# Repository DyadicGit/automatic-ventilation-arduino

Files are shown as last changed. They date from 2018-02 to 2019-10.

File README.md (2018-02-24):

# This is a Home/Flat ventilation system.
For measuring rooms air quality it uses two gas sensors MQ-9 and MQ-135 also a Thermistor for measuring temperature.
Displays gas value (unitless) and temperature (celsius) on a I2C 128x32 SSD1306 driver OLED display.
Has a two buttons:
	first button -- Toggles ON/OFF the display
	second button -- Turns on the fans for a period of time

------
Circuit:

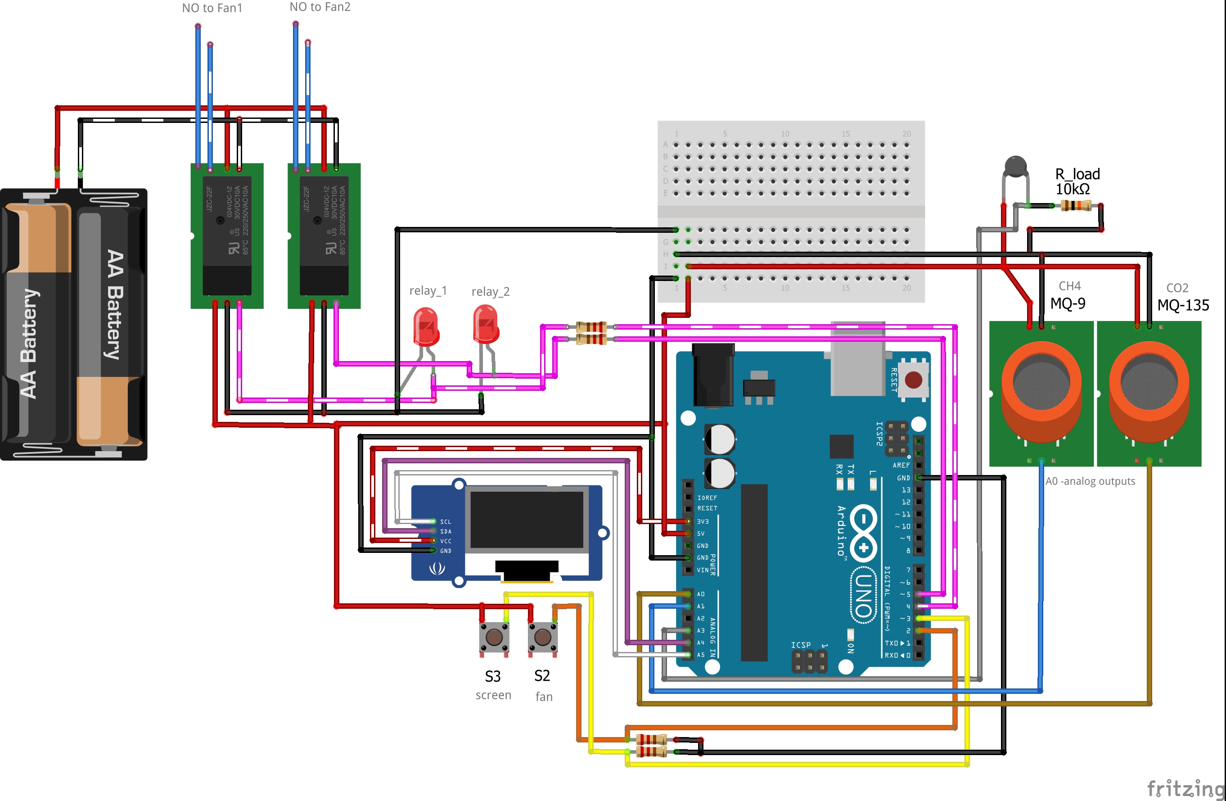
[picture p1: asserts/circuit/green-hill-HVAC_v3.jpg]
circuit: prod version circuit


## What it does?
* Automatically turns the fans ON, when the air quality goes bad (user inputs the values)
* User can turn the fans for a period of time, the remaining time is displayed on the LCD
* Toggle ON/OFF the display -- Why should it run always.

*watch a demo video below:*

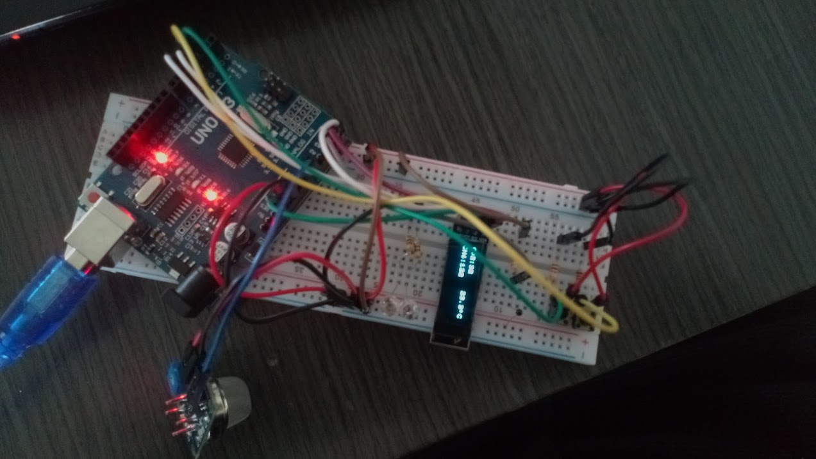
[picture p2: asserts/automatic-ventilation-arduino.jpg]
demo: open demo video (https://youtu.be/hbuPtd6k3tc)

[Demo video link](https://youtu.be/hbuPtd6k3tc)
*only one sensor in demo* :(

### Technologies used:
* For measuring temperature with a Thermistor, Steinhart–Hart equation was used
* for the OLED display [u8x8 library](https://github.com/olikraus/u8g2/wiki/u8x8reference) was used

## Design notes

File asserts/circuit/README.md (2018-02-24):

# Circuit schematics info:
Production version schematic:

prod: prod version circuit

Simulation version schematic:

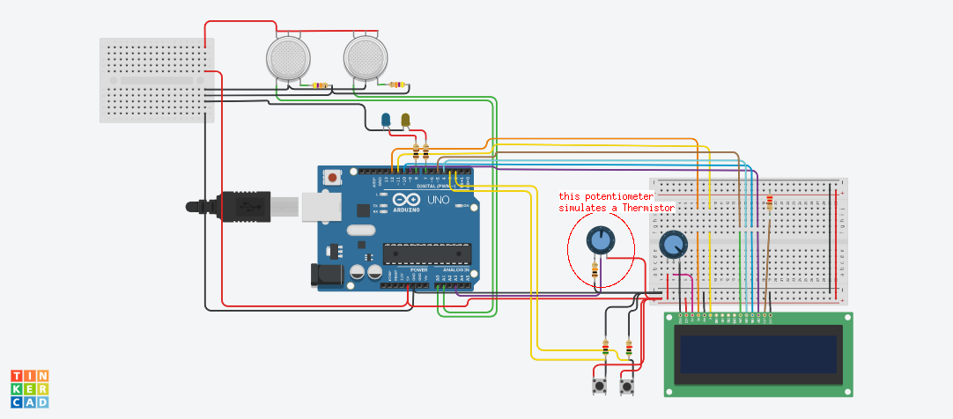
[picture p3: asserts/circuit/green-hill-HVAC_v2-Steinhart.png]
simu: simu version circuit


..Simulations where made in [Tinkercad](https://www.tinkercad.com)..
..When simulating used a potentiometer instead of the NTC thermistor, set potentiometers resistance to 10kOhm (because NTC-MF52-103 resistance is 10kOhm) also set the load resistor to 10kOhm. ..
Code for simulation is in *__asserts/other versions/main_v2-Steinhart.cpp__*
Or just test how it measures the temperature: *__asserts/other versions/test-Steinhart.cpp__*

## Bill of Materials:
1) 128x32 I2C SSD1306 OLED display

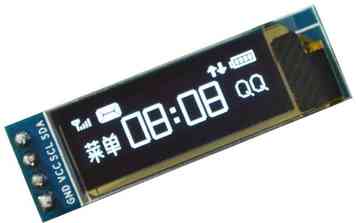
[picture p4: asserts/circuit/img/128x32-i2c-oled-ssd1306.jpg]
LCD: display


2) NTC MF52 series 103 type 10K ohm 1% Thermistor

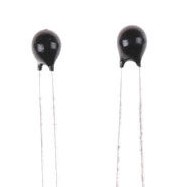
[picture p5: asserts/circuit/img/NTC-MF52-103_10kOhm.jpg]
Thermistor: NTC MF52 103


3) 10K Ohm resistor (Thermistors load resistance)

4) MQ-9 Gas sensor

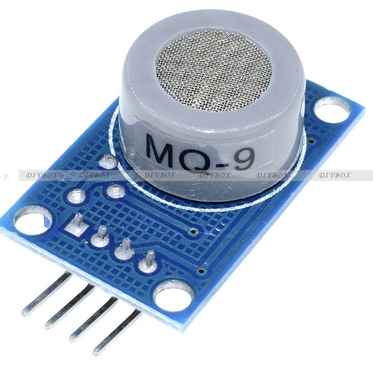
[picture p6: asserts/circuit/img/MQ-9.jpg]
MQ-9: MQ-9 Gas sensor


5) MQ-135 Gas sensor

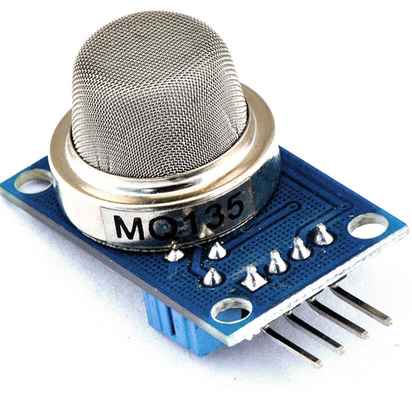
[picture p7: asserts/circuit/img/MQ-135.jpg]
MQ-135: MQ-135 Gas sensor


6) 2x Momentary buttons
7) 2x resistors for those buttons
8) 2x LED (for indication)
9) 2x resistors for those LEDS (remember R = (U-U_led)/I, for a white/blue LED R=(5-3)/0.02)
10) Arduino UNO R3 or Atmega328P

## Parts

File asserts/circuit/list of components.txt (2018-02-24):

Bill of Materials:
1) 128x32 I2C SSD1306 OLED display
2) NTC MF52 series 103 type 10K ohm 1% Thermistor
3) 10K Ohm resistor (Thermistor load resistance)
4) MQ-9 Gas sensor
5) MQ-135 Gas sensor
6) 2x Momentary buttons
7) 2x resistors for those buttons
8) 2x LED (for indication)
9) 2x resistors for those LEDS (remember R = (U-U_led)/I, for a white/blue LED R=(5-3)/0.02)
10) Arduino UNO R3 or Atmega328P

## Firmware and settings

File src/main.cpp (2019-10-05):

#include <Arduino.h>
#include <U8x8lib.h>
#include "../lib/icons/Icons.h"
#include "../lib/SteinhartHartEquation/SteinhartHartEquation.h"

//User variables:
const int loopEvery = 2000;                                                         //<-- set time to read the value every (in miliseconds)
const int gasValueCO2 = 120;                                                       // <-- set this when to clear the air
const int gasValueCH4 = 340;                                                       // <-- set this when to clear the air
const unsigned long int fanManualWorkTime = (unsigned long int)1000 * 60 * 60;    // set manual fan working time
const unsigned long int fanTurboModeWorkTime = (unsigned long int)1000 * 60 * 35;  // set fan on turbo mode working time, should be less tan fanManualWorkTime!
                                                                                   // ex.: fanManualWorkTime=60min & fanTurboModeWorkTime=45min, then the fan will work 15mins in turbo mode,the it'll switch to low speed
const unsigned long int fanAutomaticWorkTime = (unsigned long int)1000 * 60 * 30; // set automatic fan working time
const unsigned long debounceIgnore = 150;                                          // If button press come faster than 50ms ("this variable"), assume it's a bounce and ignore

//machines variables:
const int sensorCO2Pin = A0;
const int sensorCH4Pin = A1;
const int sensorTempPin = A3;
float sensorTempVin = 5;                //Volts (Voltage of the microcontoroller)
float sensorTempLoadResistance = 10000; //Ohms
const int relay1FanPin = 4;
const int relay2TurboModePin = 5;
const int ledFan1Pin = 6;
const int buttonLCDPin = 3;
const int buttonFanPin = 2;
const byte ON = LOW;
const byte OFF = HIGH;
///calculation variables:
int sensorCO2Read;
int sensorCH4Read;
float sensorTempRead;
float sensorTempValue;
String previouseSensorCO2Value;
String previouseSensorCH4Value;
String previouseSensorTempValue;
uint8_t rowCO2 = 0;
uint8_t rowCH4 = 2;
uint8_t rowTemp = 1;
const int column = 8;
//state variables:
volatile byte LCDState = HIGH;
volatile byte fanState = LOW;
// time calculation variables:
unsigned long int currentMillis = 0;
unsigned long int loopEveryPreviouseMillis = 0;
unsigned long int delayByMillisPreviouse = 0;
//LCD declaration section
U8X8_SSD1306_128X32_UNIVISION_SW_I2C u8x8(/* clock=A5*/ 19, /* data=A4*/ 18);

//**initialize to count the Steinhart–Hart equations coefficients:
//** values taken from "NTC Thermistors - Murata" datasheet page:15,
//** for a NTC MF52-series 103-type 10kOhm Thermistor (Proteus device code: NCP21XV103)
SteinhartHartEquation sensorTemp(/*T1*/ 5, /*R1*/ 25194, /*T2*/ 25, /*R2*/ 10000, /*T3*/ 45, /*R3*/ 4401);

//function declaration section
void debounce(void (*)(), unsigned long debounceIgnore);
void readButtons();
void toggleStateLCD();
void toggleStateFan();
void handleFan();
void turnOnOffLCD();
bool isLoopTime();
bool isDelayTime(unsigned long int delayByMillis);
void printValuesOnLCD();
void clearValuesOnLCD();
String getHoursMinsSecs(int seconds);
void showWhoTrigerredFan(bool printIt);
float getResistance(float ADCread, float Vin, float R_load);

void setup()
{
  pinMode(sensorCO2Pin, INPUT);
  pinMode(sensorCH4Pin, INPUT);
  pinMode(sensorTempPin, INPUT);
  pinMode(relay1FanPin, OUTPUT);
  pinMode(relay2TurboModePin, OUTPUT);
  pinMode(ledFan1Pin, OUTPUT);
  //momentary buttons
  pinMode(buttonLCDPin, INPUT);
  pinMode(buttonFanPin, INPUT);
  //set initial output pins state
  digitalWrite(relay1FanPin, OFF);
  digitalWrite(relay2TurboModePin, OFF);
  digitalWrite(ledFan1Pin, LOW);
  // set up the LCD:
  u8x8.begin();
  u8x8.setPowerSave(0);
  // Print a welcome message on the LCD.
  u8x8.setFont(u8x8_font_pxplusibmcgathin_f);
  u8x8.print("Studios 83");
  u8x8.drawTile(1, 2, 1, Icons::house);
  delay(1000);
  for (uint8_t i = 10; i < 13; i++)
  {
    u8x8.setCursor(i, 0);
    u8x8.print(".");
    delay(800);
  }
}

void loop()
{
  currentMillis = millis();
  if (currentMillis < loopEvery + 2027)
  {                                        // this code line is just to display that the machine works when it stats for the first time
    u8x8.drawTile(15, 4, 1, Icons::house); // "2027" is a variable I've got when simulating (experimental principal)
  }
  readButtons();
  turnOnOffLCD();

  if (fanState)
  {
    handleFan();
  }

  if (isLoopTime())
  {
    sensorCO2Read = analogRead(sensorCO2Pin);
    sensorCO2Read = floor(sensorCO2Read / 10) * 10;
    sensorCH4Read = analogRead(sensorCH4Pin);
    sensorCH4Read = floor(sensorCH4Read / 10) * 10;
    sensorTempRead = analogRead(sensorTempPin);
    float sensorTempResistance = getResistance(sensorTempRead, sensorTempVin, sensorTempLoadResistance);
    sensorTempValue = sensorTemp.getTempCelsius(sensorTempResistance);

    clearValuesOnLCD();
    printValuesOnLCD();

    if (sensorCO2Read >= gasValueCO2 || sensorCH4Read >= gasValueCH4)
    {
      digitalWrite(relay1FanPin, ON);
      digitalWrite(relay2TurboModePin, OFF);
      digitalWrite(ledFan1Pin, HIGH);

      showWhoTrigerredFan(true);
      delayByMillisPreviouse = 0;
      unsigned long int timeCounter = fanAutomaticWorkTime;
      while (timeCounter > 0 && !fanState)
      {
        readButtons();
        turnOnOffLCD();
        if (isDelayTime(1))
        {
          timeCounter--;
        }
      }
      showWhoTrigerredFan(false);
    }
    else
    {
      digitalWrite(relay1FanPin, OFF);
      digitalWrite(relay2TurboModePin, OFF);
      digitalWrite(ledFan1Pin, LOW);
    }

    previouseSensorCO2Value = (String)sensorCO2Read;
    previouseSensorCH4Value = (String)sensorCH4Read;
    previouseSensorTempValue = (String)sensorTempValue;
  } //if isLoopTime();
} //main loop

//time calculation functions
bool isLoopTime()
{
  bool result = currentMillis - loopEveryPreviouseMillis >= loopEvery;
  if (result)
  {
    loopEveryPreviouseMillis = currentMillis;
  }
  return result;
}
bool isDelayTime(unsigned long int delayByMillis)
{
  currentMillis = millis();
  bool result = (currentMillis - delayByMillisPreviouse >= delayByMillis) || (currentMillis < delayByMillis);
  if (result)
  {
    delayByMillisPreviouse = currentMillis;
  }
  return result;
}

//state toggle functions
void toggleStateLCD()
{
  LCDState = !LCDState;
}
void toggleStateFan()
{
  fanState = !fanState;
}
void debounce(void (*handleStateFun)(), unsigned long debounceIgnore)
{
  static unsigned long last_interrupt_time = 0;
  unsigned long interrupt_time = millis();
  if (interrupt_time - last_interrupt_time > debounceIgnore)
  {
    (*handleStateFun)();
  }
  last_interrupt_time = interrupt_time;
}
void readButtons()
{
  if (digitalRead(buttonLCDPin) == HIGH)
  {
    debounce(toggleStateLCD, debounceIgnore);
  }
  if (digitalRead(buttonFanPin) == HIGH)
  {
    debounce(toggleStateFan, debounceIgnore);
  }
}

// action handling functions
void handleFan()
{
  digitalWrite(relay1FanPin, ON);
  digitalWrite(relay2TurboModePin, ON);
  digitalWrite(ledFan1Pin, HIGH);

  int timeCounter = (int)round(fanManualWorkTime / 1000);
  u8x8.clearDisplay();
  u8x8.setCursor(0, 0);
  u8x8.print("fan working T");
  u8x8.drawTile(14, 2, 2, Icons::ventilator16x16_1of2);
  u8x8.drawTile(14, 3, 2, Icons::ventilator16x16_2of2);
  u8x8.setCursor(1, 2);
  u8x8.print(getHoursMinsSecs(timeCounter));
  delayByMillisPreviouse = 0;
  while (timeCounter >= 0 && fanState)
  {
    if (isDelayTime(1000))
    {
      u8x8.setCursor(1, 2);
      u8x8.print(getHoursMinsSecs(timeCounter));
      if (timeCounter < 10000)
      {
        u8x8.print("    ");
      }
      timeCounter--;
    }
    if (timeCounter <= (int)round(fanTurboModeWorkTime / 1000))
    {
      digitalWrite(relay2TurboModePin, OFF);

      u8x8.setCursor(0, 0);
      u8x8.print("fan working  ");
    }
    readButtons();
    turnOnOffLCD();
  }
  u8x8.clearDisplay();
  printValuesOnLCD();
  fanState = LOW;
}

void turnOnOffLCD()
{
  u8x8.setPowerSave(!LCDState);
}

void printValuesOnLCD()
{
  //print CO2 sensor value on LCD
  u8x8.setCursor(0, rowCO2);
  u8x8.print("CO2:");
  u8x8.setCursor(4, rowCO2);

  u8x8.print(sensorCO2Read);
  //print CH4 sensor value on LCD
  u8x8.setCursor(0, rowCH4);
  u8x8.print("CH4:");
  u8x8.setCursor(4, rowCH4);
  u8x8.print(sensorCH4Read);
  //print "temp" value on LCD
  u8x8.setCursor(10, rowTemp);
  String strg = String(sensorTempValue, 1) + (char)0xB0 + "C";
  u8x8.print(strg);
}

void clearValuesOnLCD()
{
  //clears the screen if length of values changed
  String strSensorCO2Value = (String)sensorCO2Read;
  String strSensorCH4Value = (String)sensorCH4Read;
  String strSensorTempValue = (String)sensorTempValue;
  if (previouseSensorCO2Value.length() != strSensorCO2Value.length() ||
      previouseSensorCH4Value.length() != strSensorCH4Value.length() ||
      previouseSensorTempValue.length() != strSensorTempValue.length())
  {
    u8x8.clearDisplay();
  }
}
String getHoursMinsSecs(int seconds)
{
  int hoursRemaining = seconds / 3600;
  int minutesRemaining = (seconds % 3600) / 60;
  int secondsRemaining = seconds % 60;

  return (hoursRemaining != 0 ? (String)hoursRemaining + "h " : "") + (minutesRemaining != 0 ? (String)minutesRemaining + "m" : "") + (secondsRemaining != 0 ? (String)secondsRemaining + "s" : "");
};

void showWhoTrigerredFan(bool printIt)
{
  if (printIt)
  {
    if (sensorCO2Read >= gasValueCO2)
    {
      u8x8.drawTile(column, rowCO2, 1, Icons::ventilator8x8);
    }
    if (sensorCH4Read >= gasValueCH4)
    {
      u8x8.drawTile(column, rowCH4, 1, Icons::ventilator8x8);
    }
  }
  if (!printIt)
  {
    u8x8.drawString(column, rowCO2, " ");
    u8x8.drawString(column, rowCH4, " ");
  }
}

float getResistance(float ADCread, float Vin, float R_load)
{
  float Vout = (ADCread * Vin) / 1024;
  return R_load * ((Vin / Vout) - 1);
};

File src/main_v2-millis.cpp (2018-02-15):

#include <Arduino.h>
#include <LiquidCrystal.h>
//User values
const int loopEvery = 400;  //<-- set time to read the value every (in mili seconds)
const int gasValue = 800; // <-- set this when to clear the air
const unsigned long int fanManualWorkTime = 8000;       // set manual fan working time
const unsigned long int fanAutomaticWorkTime = 500;    // set automatic fan working time
///machine value declaration ////
int sensorCO2Value;
int sensorCH4Value;
int sensorTempValue;
//previouse values
String previouseSensorCO2Value;
String previouseSensorCH4Value;
String previouseSensorTempValue;
//
int sensorCO2Pin = 0;
int sensorCH4Pin = 1;
int sensorTempPin = 6;
int relay1Pin = 7;
int relay2Pin = 8;
// time calculation variables
unsigned long int currentMillis = 0;
unsigned long int loopEveryPreviouseMillis = 0;
unsigned long int delayByMillisPreviouse = 0;
//button debounce declaration section using interrupts (for Arduino UNO!)
const int buttonLCDPin = 3;
const int buttonFanPin = 2;
volatile byte LCDState = HIGH;         // the initial state of the output pin
volatile byte fanState = LOW;         // the initial state of the output pin
//LCD declaration section
const int rs = 12, en = 11, d4 = 5, d5 = 4, d6 = 10, d7 = 9;
LiquidCrystal lcd(rs, en, d4, d5, d6, d7);

//function declaration section
void toggleStateLCD();
void handleLCDInterrupt();
void handleFanInterrupt();
void toggleStateFan();
void handleFan();
bool isLoopTime();
bool isDelayTime(unsigned long int delayByMillis);
void printValuesOnLCD();
void clearValuesOnLCD();
void printValuesOnSerial();
void turnOnOffLCD();

void setup() {
  Serial.begin(9600);      // sets the serial port to 9600
  pinMode(sensorCO2Pin, INPUT);
  pinMode(sensorCH4Pin, INPUT);
  pinMode(sensorTempPin, INPUT);
  pinMode(relay1Pin, OUTPUT);
  pinMode(relay2Pin, OUTPUT);
  //momentary buttons
  pinMode(buttonLCDPin, INPUT);  //LCD on/off momentary button
  pinMode(buttonFanPin, INPUT);  //fan on button
  //set initial output pins state
  digitalWrite(relay1Pin, LOW);
  digitalWrite(relay2Pin, LOW);

  attachInterrupt(digitalPinToInterrupt(buttonLCDPin), handleLCDInterrupt, CHANGE);
  attachInterrupt(digitalPinToInterrupt(buttonFanPin), handleFanInterrupt, CHANGE);
  // set up the LCD's number of columns and rows:
  lcd.begin(16, 2);
  // Print a welcome message to the LCD.
  lcd.print("Studios83");
  delay(500);
  for(uint8_t i=9; i<12; i++) {
    lcd.setCursor(i, 0);
    lcd.print(".");
    delay(500);
  }
}

void loop() {
  currentMillis = millis();
  if (currentMillis < loopEvery+2027) {lcd.blink();} else {lcd.noBlink();}  // this code line is just to display that the machine works when it stats for the first time
                                                                          // "2027" is a variable I've got when simulating (experimental principal)
  turnOnOffLCD();

  if (fanState) {handleFan();}

  if (isLoopTime()) {
    // read values from sensors:
    sensorCO2Value = analogRead(sensorCO2Pin);
    sensorCH4Value = analogRead(sensorCH4Pin);
    sensorTempValue = analogRead(sensorTempPin);

    if (LCDState) {
      clearValuesOnLCD();
    }
    if (LCDState) {
      printValuesOnLCD();
    }
    printValuesOnSerial();

    if (sensorCO2Value > gasValue || sensorCH4Value > gasValue) {
      digitalWrite(relay1Pin, HIGH);
      digitalWrite(relay2Pin, HIGH);

      if (LCDState) { lcd.setCursor(15, 1); }
      delayByMillisPreviouse = 0;
      int timeCounter = fanAutomaticWorkTime;
      while (timeCounter>0 && !fanState) {
        if (LCDState) { lcd.blink(); }  //shows that fan is ON
        turnOnOffLCD();
        if (isDelayTime(1)) {
          timeCounter--;
        }
      }
      if (LCDState) { lcd.noBlink(); }
    } else {
      digitalWrite(relay1Pin, LOW);
      digitalWrite(relay2Pin, LOW);
    }

    previouseSensorCO2Value = (String) sensorCO2Value;
    previouseSensorCH4Value = (String) sensorCH4Value;
    previouseSensorTempValue = (String) sensorTempValue;
  } //if isLoopTime();
}  //main loop

//time calculation functions
bool isLoopTime() {
  bool result = currentMillis - loopEveryPreviouseMillis >= loopEvery;
  if (result) {loopEveryPreviouseMillis = currentMillis;}
  return result;
}
bool isDelayTime(unsigned long int delayByMillis) {
  currentMillis = millis();
  bool result = (currentMillis - delayByMillisPreviouse >= delayByMillis) || (currentMillis < delayByMillis);
  if (result) {delayByMillisPreviouse = currentMillis;}
  return result;
}

//state toggle functions
void toggleStateLCD() {
  LCDState = !LCDState;
}
void toggleStateFan() {
  fanState = !fanState;
}

void handleLCDInterrupt() {
  static unsigned long last_interrupt_time = 0;
  unsigned long interrupt_time = millis();
  // If button press come faster than 50ms, assume it's a bounce and ignore
  if (interrupt_time - last_interrupt_time > 50)
    {
      toggleStateLCD();
    }
  last_interrupt_time = interrupt_time;
}
void handleFanInterrupt() {
  static unsigned long last_interrupt_time = 0;
  unsigned long interrupt_time = millis();
  if (interrupt_time - last_interrupt_time > 50)
    {
      toggleStateFan();
    }
  last_interrupt_time = interrupt_time;
}

// action handling functions
void handleFan() {
  digitalWrite(relay1Pin, HIGH);
  digitalWrite(relay2Pin, HIGH);

  int timeCounter = (int) round(fanManualWorkTime/1000);
  lcd.clear();
  lcd.setCursor(0, 0);
  lcd.print("fan working");
  lcd.setCursor(0, 1);
  lcd.print(timeCounter);
  delayByMillisPreviouse = 0;
  while (timeCounter>=0 && fanState) {
    if (isDelayTime(1000)) {
      if (LCDState) {
        lcd.setCursor(0, 1);
        lcd.print(timeCounter);
        if (timeCounter < 10000) {lcd.print("    ");}
      }
      timeCounter--;
    }
    turnOnOffLCD();
  }
  lcd.clear();
  printValuesOnLCD();
  fanState = LOW;
}

void turnOnOffLCD() {    //used also to handle LCD toggling not in main loop
  if (LCDState) {
    lcd.display();
  } else {
    lcd.noDisplay();
  }
}

//other functions
void printValuesOnSerial() {
  Serial.print("CO2: ");
  Serial.println(sensorCO2Value, DEC);
  Serial.print("CH4: ");
  Serial.println(sensorCH4Value, DEC);
  Serial.print("temp: ");
  Serial.print(sensorTempValue*5/1024, DEC);
  Serial.println("*C");
}

void printValuesOnLCD() {
  //print CO2 sensor value on LCD
    lcd.setCursor(0, 0);
    lcd.print("CO2:");
    lcd.setCursor(4, 0);
    lcd.print(sensorCO2Value);
  //print CH4 sensor value on LCD
    lcd.setCursor(0, 1);
    lcd.print("CH4:");
    lcd.setCursor(4, 1);
    lcd.print(sensorCH4Value);
  //print "temp" value on serial
    lcd.setCursor(10, 0);
    lcd.print("temp:");
    lcd.setCursor(10, 1);
    lcd.print(sensorTempValue*5/1024);
    lcd.print((char)178); //degree symbol
    lcd.print("C");
}
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

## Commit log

2018-02-24 main_v3 works in life
    [green-hill-HVAC.fzz, home HVAC.brd]
2018-09-10 filled in gas sensors real data
2019-04-27 add LED indicator, revert output for relay pins, add fan Turbo speed control
    [main.cpp]
2019-04-27 fix electric field triggering the interrupts
    [main.cpp]
2019-07-03 just geniuse!
    RESOLUTION:
    make a delay before each digitalWrite() for relays, so that the generated EMI from relays trigerred could just pass by,
    this way the interrupts won't be triggered from electro magnetic noise
    [main.cpp]
2019-07-04 display timerCounter in hours, minutes, seconds not only seconds
2019-07-04 don't use interupts on projects with 220V AC current
    Use debounde function in main loop,
    examples added
2019-07-04 fix mistypes, set PROD variables
    [main.cpp]
